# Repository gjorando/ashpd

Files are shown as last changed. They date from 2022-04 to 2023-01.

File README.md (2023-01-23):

# Aperture Science Handheld Portal Device

This repository contains everything needed to craft your very own Portal Gun — at home! 

**WARNING: This build is in alpha state. There are a lot of issues and some tinkering may be needed to get an assembled device.**

## Repository tree

* `ashpd_firmware/`: Micropython code that runs on an ESP32. The firmware handles some lights and sound effects. A PyCharm project is included, ready to use. I use the MicroPython plug-in to quickly deploy and test my code directly from PyCharm.
* `ashpd_hardware/`: A KiCad (free and open source EDA suite) project I used to design the electronic schematic. A GIMP project (`protoboard layout.xcf`) crudely describes the disposition I picked for the components on a protoboard.
* `decals/`: Vinyl decal designs that I quickly put together. They have kind of an odd format because I sent them for manufacturing to [Sticker mule](https://www.stickermule.com/), which only accepts multiples of 25mm for the size.
* `ender3_cura`: Ultimaker Cura settings for each piece. They are tuned for my own Ender3-V2 printer, so be careful if you want to print the pieces yourself.
* `stl_files`: STL files for each piece. I'd recommend using these files if you want to print them yourself. Import them into your slicer of choice, and fine tune the settings according to what works best for you.
* `portal_gun.FCStd`: The main FreeCAD project which holds the design of each 3D printed component.

## History of the project

## Instructions manual

Coming soon...

### Materials and tools

### 3D printing

### Electronics

### Painting and decoration

### Assembly

## Aknowledgments

* Portal and the Portal logo are trademarks and/or registered trademarks of Valve Corporation. All other trademarks are property of their respective owners. © 2023 Valve Corporation. All rights reserved.
* A huge thank you to [Lucas Lombard](https://github.com/lululombard) for his advice and material support during the conception and construction of this project. I couldn't have done it without you.

## TODO list: minor pieces

- [ ] speaker cover
- [ ] LED ring holder for the barrel
- [ ] LED holder for the rod
- [ ] USB-C support if I cannot manage to make the current cable work

## Roadmap for a V2

* Rebuild from the ground each piece (on either FreeCad or Fusion 360), being more mindful of the dependencies between each operation. The current FreeCAD file is a mess and trying to change some values can break everything.
* Add â way of atemporarily fixing each pièce together instead of relying on hot glue. Actually, the v1 uses heat sealed threaded inserts, but it was a last minute decision that was haphazardly put together. Adding pre-holes for the threaded inserts would be a plus.
* On the rear core lid: add a conduit to directly screw the handle's bottom screw, instead of hacking something with a threaded insert to correct for a design oversight.
* Adjust the tolerance, which was waaay too small: a lot of pieces have to be sanded a lot to fit together.
* Add more cake.

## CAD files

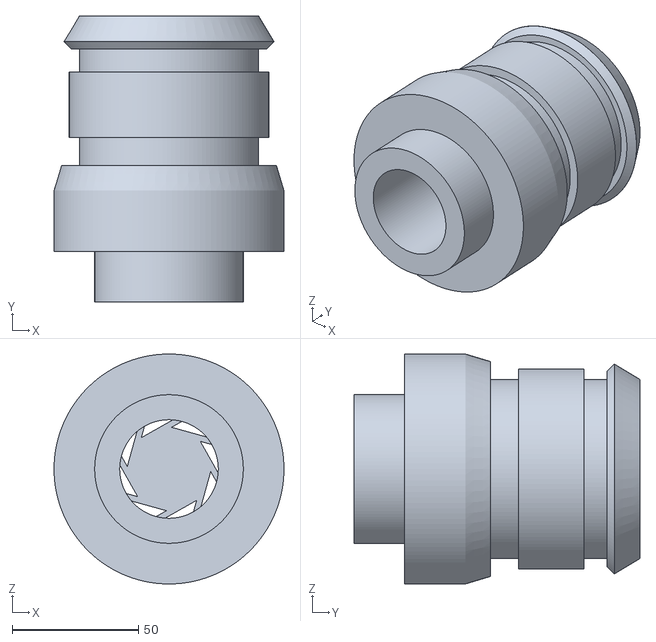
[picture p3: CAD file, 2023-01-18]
stl_files/barrel_main.stl
91.0 x 113.0 x 91.0

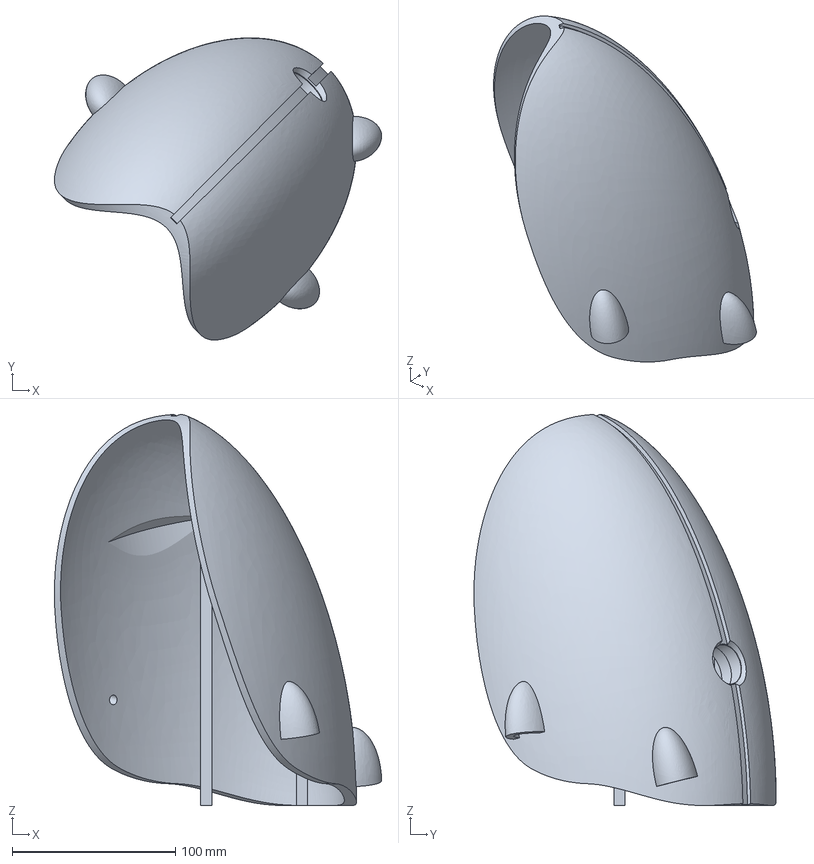
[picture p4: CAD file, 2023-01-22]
ender3_cura/rear_shell.3mf
200.2 x 184.9 x 239.3 mm

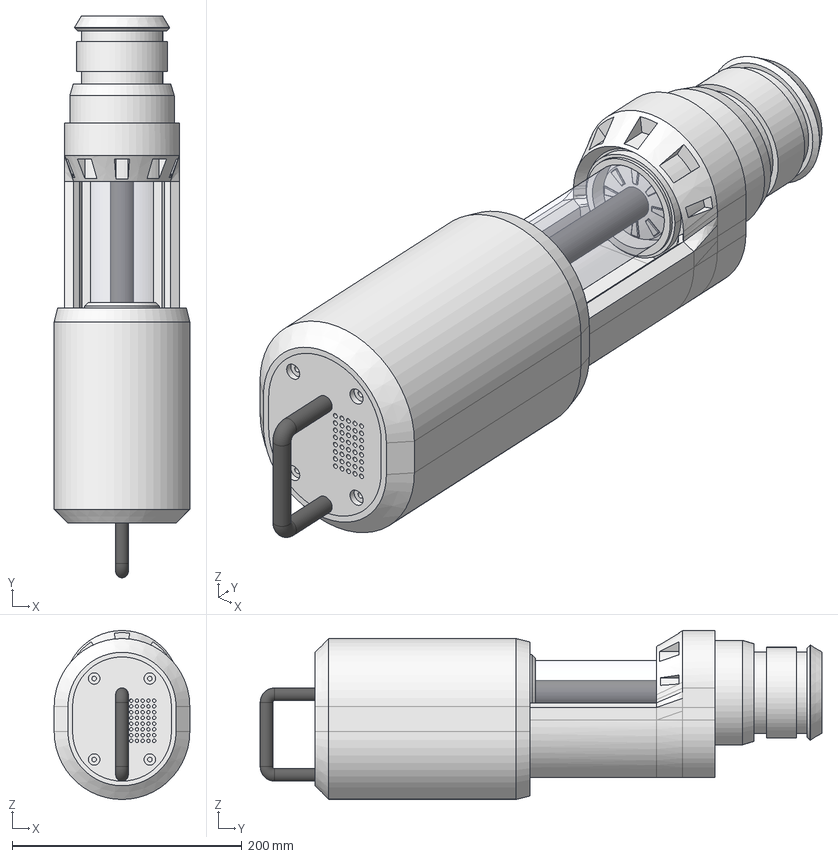
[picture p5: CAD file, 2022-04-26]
freecad/portal_gun.FCStd
118.0 x 488.5 x 147.0 mm
rear_core_body
rear_core_lid
front_core_body
barrel_main
trans_tube
light_rod_body
handle

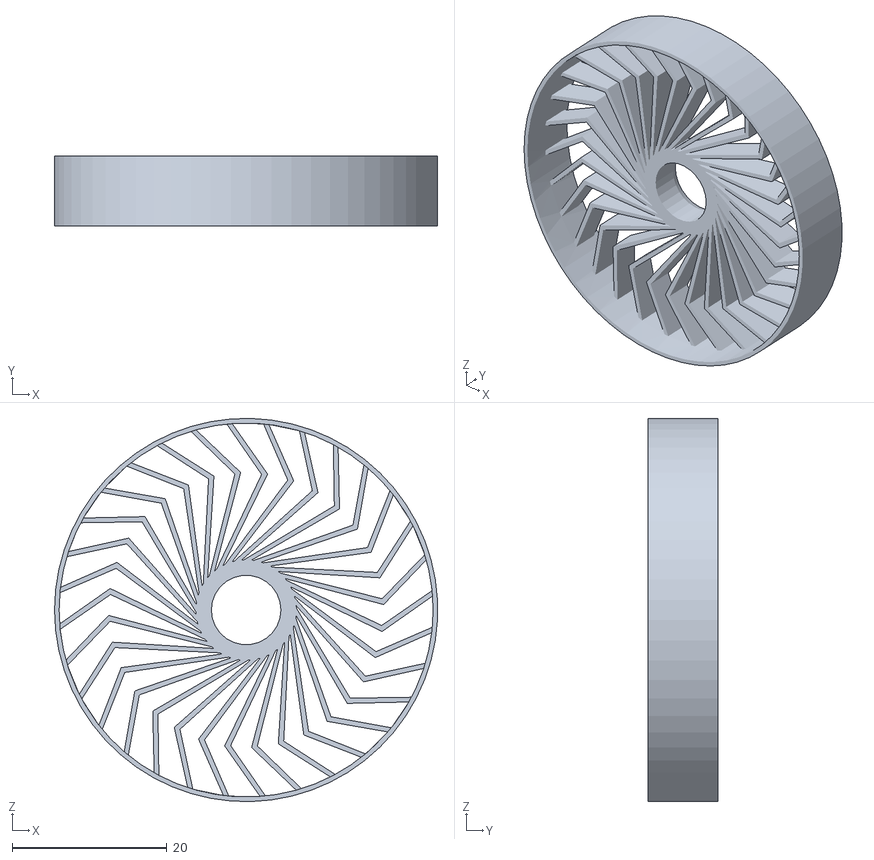
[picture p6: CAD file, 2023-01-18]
stl_files/barrel_pattern.stl
49.6 x 9.00 x 49.6

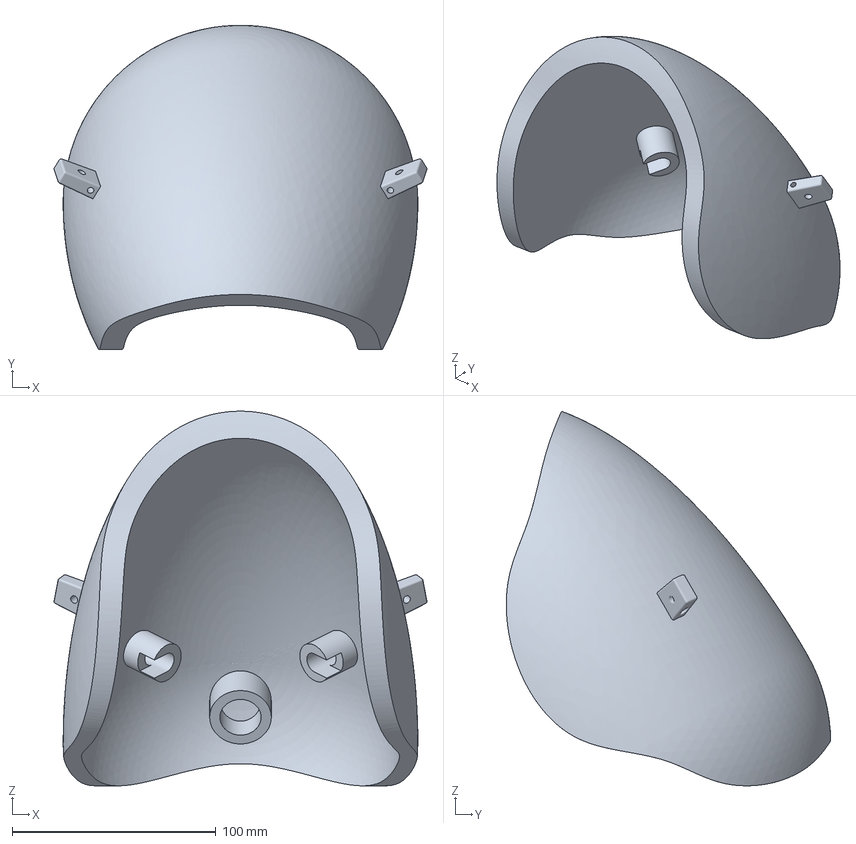
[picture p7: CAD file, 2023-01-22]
ender3_cura/front_shell.3mf
182.9 x 159.1 x 183.7 mm

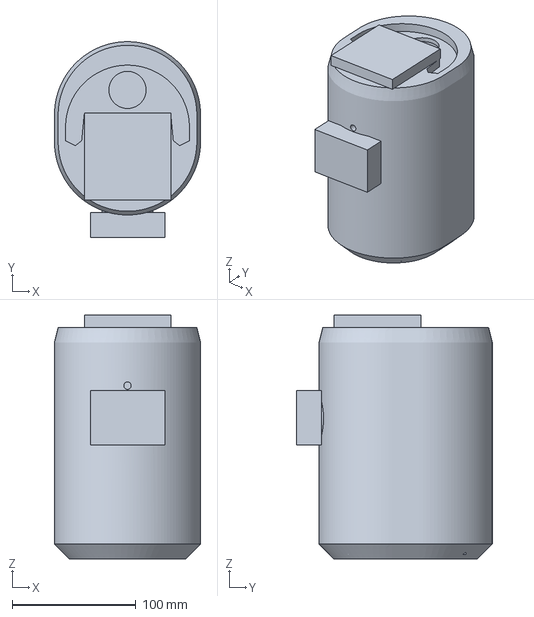
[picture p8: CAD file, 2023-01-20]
ender3_cura/rear_core.3mf
118.0 x 158.0 x 197.1 mm

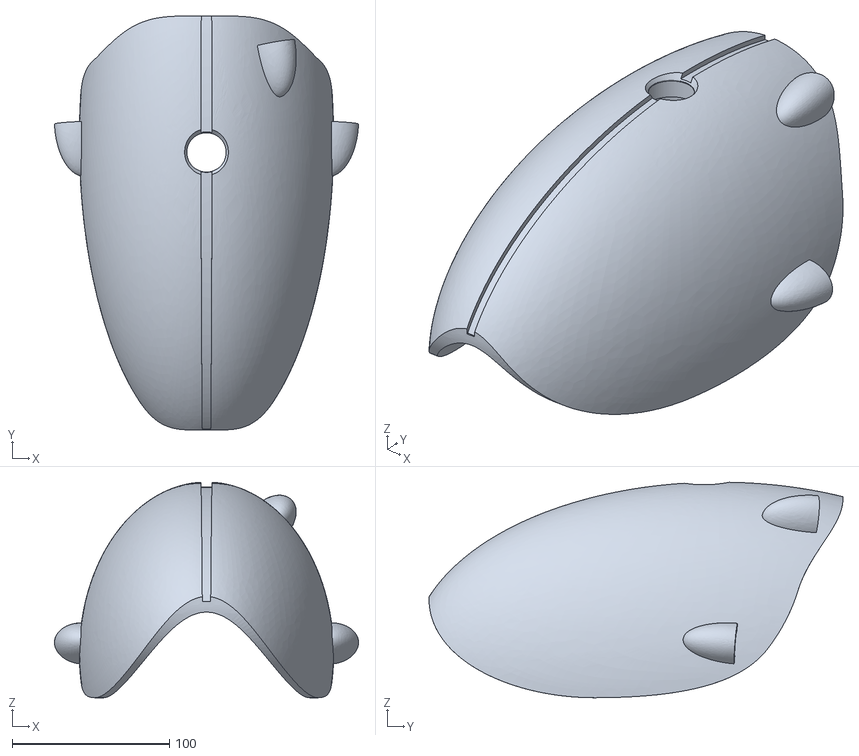
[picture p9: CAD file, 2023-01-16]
stl_files/rear_shell.stl
193.7 x 263.7 x 137.3

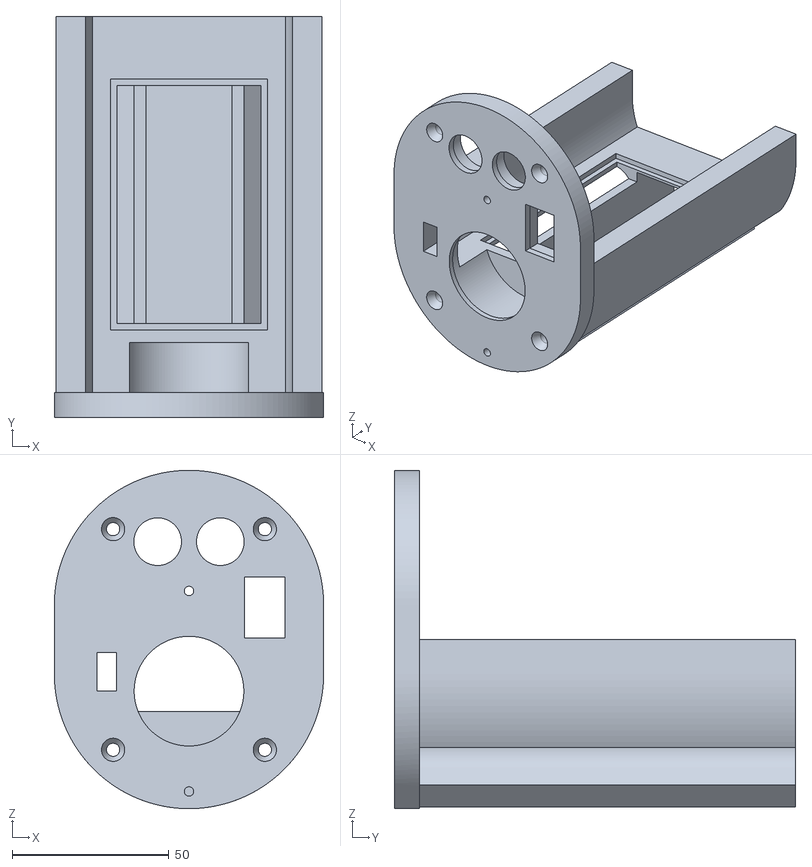
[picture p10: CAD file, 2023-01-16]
stl_files/rear_core_lid.stl
86.0 x 128.0 x 108.0

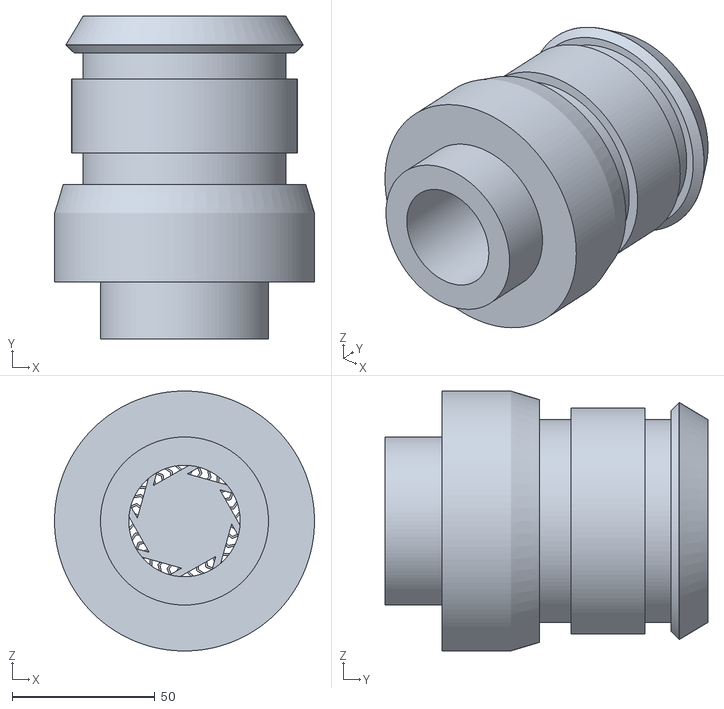
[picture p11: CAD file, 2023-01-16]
stl_files/barrel.stl
91.0 x 113.0 x 91.0

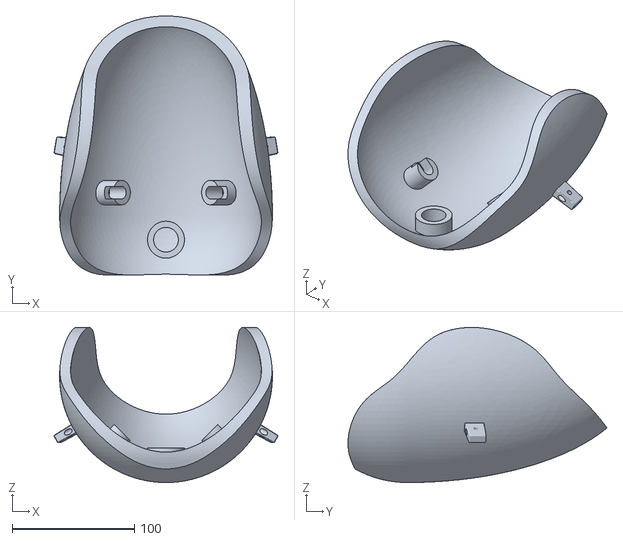
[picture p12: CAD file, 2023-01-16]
stl_files/front_shell.stl
182.9 x 211.7 x 126.8

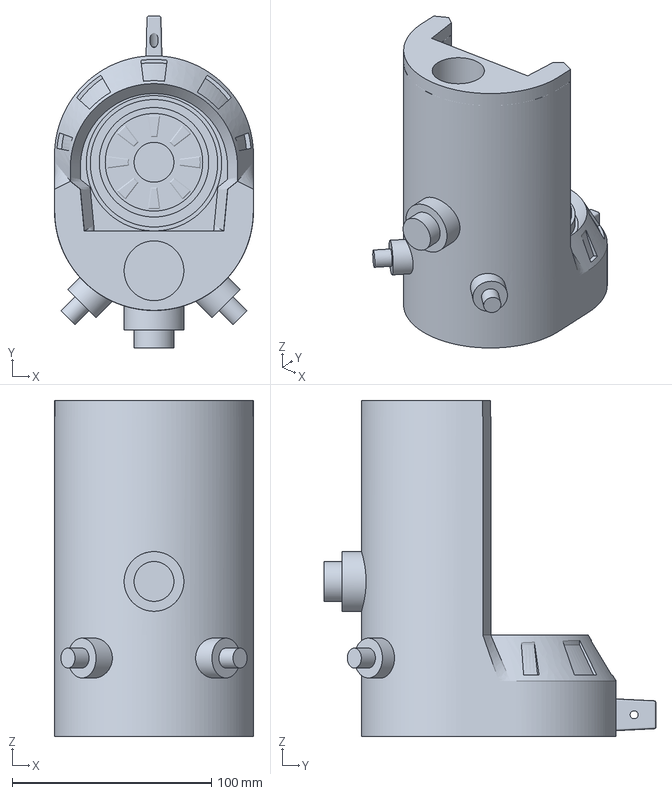
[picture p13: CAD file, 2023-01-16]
ender3_cura/front_core.3mf
100.0 x 166.8 x 169.0 mm

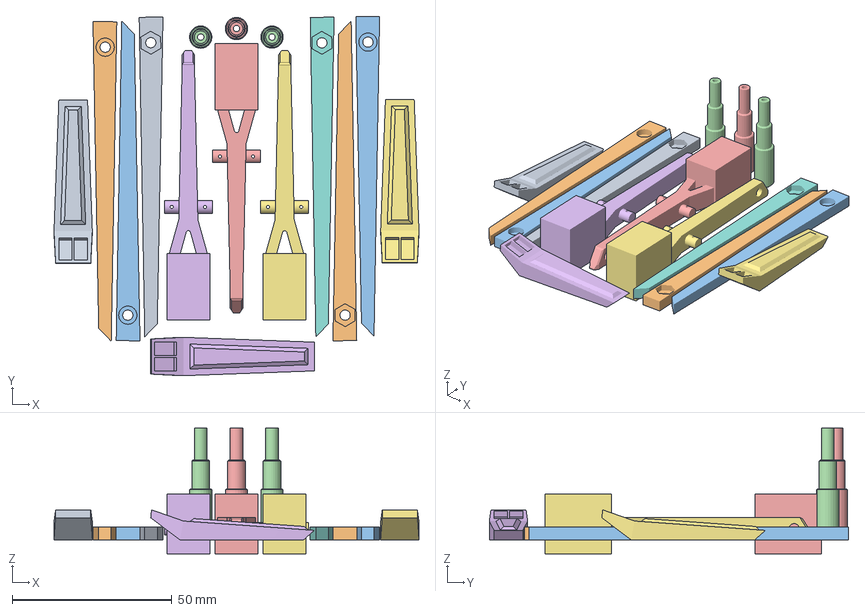
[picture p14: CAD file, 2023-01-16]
ender3_cura/fingers.3mf
114.2 x 112.5 x 39.4 mm
finger_tip.stl
finger_body_R.stl
finger_body_L.stl
finger_insert.stl
finger_base.stl
finger_tip.stl(1)
finger_tip.stl(2)
finger_body_R.stl(1)
finger_body_R.stl(2)
finger_body_L.stl(1)
finger_body_L.stl(2)
finger_insert.stl(1)
finger_insert.stl(2)
finger_base.stl(1)
finger_base.stl(2)

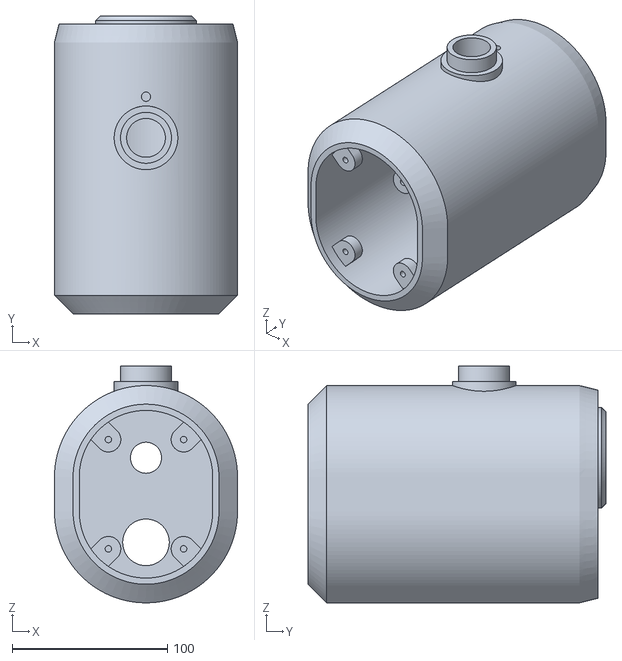
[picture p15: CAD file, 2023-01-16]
stl_files/rear_core.stl
118.0 x 192.0 x 152.5

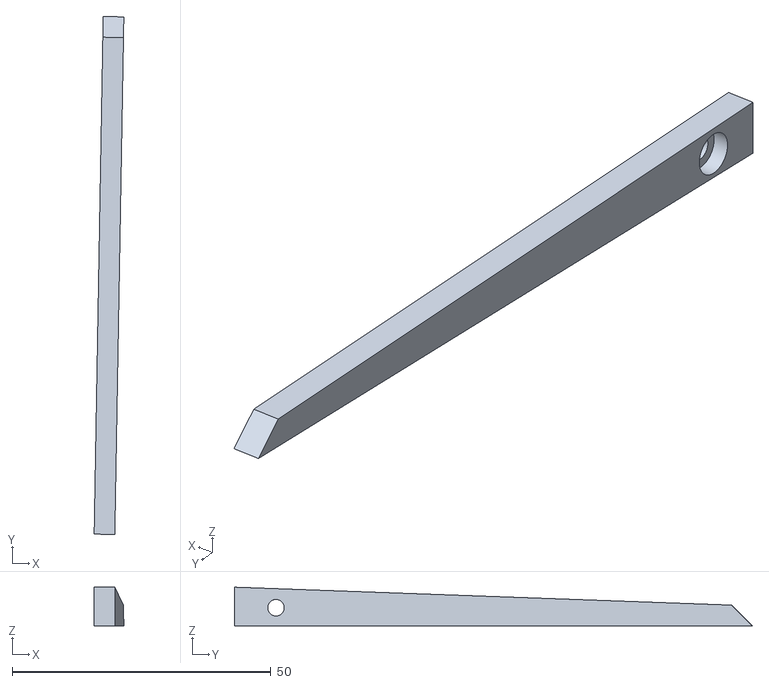
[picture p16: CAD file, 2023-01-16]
stl_files/finger_body_L.stl
5.74 x 100.1 x 7.47

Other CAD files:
ender3_cura/barrel_pattern.3mf
ender3_cura/barrel.3mf
ender3_cura/rear_core_lid.3mf
stl_files/front_core.stl
source_portal_gun.blend
stl_files/finger_base.stl
stl_files/finger_body_R.stl
stl_files/finger_insert.stl
stl_files/finger_tip.stl

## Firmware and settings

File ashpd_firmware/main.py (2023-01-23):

import machine
import neopixel

from wavplayer import WavPlayer

import micropython
micropython.alloc_emergency_exception_buf(100)

# portal colors (please use hexadecimal bytes as Python can autoparse decimal values to 32bit integers)
ORANGE_COLOR = (0xFF, 0x20, 0x00)
BLUE_COLOR = (0x00, 0x65, 0xFF)
# total number of LEDs driven
NUM_LED_STRIP = 32
# timing (high_0, low_0, high_1, low_1)
LED_STRIP_TIMING = (350, 800, 700, 600)

def orange_callback(p):
    """
    Callback for the orange button.

    :param p: Pin.
    """
    global AUDIO_PLAYER
    if AUDIO_PLAYER.isplaying():  # This avoids change while the sound is still playing
        return
    global current_color
    global portal_sound
    portal_sound = "fire_orange.wav"
    current_color = ORANGE_COLOR


def blue_callback(p):
    """
        Callback for the blue button.

        :param p: Pin.
        """
    global AUDIO_PLAYER
    if AUDIO_PLAYER.isplaying():  # This avoids change while the sound is still playing
        return
    global current_color
    global portal_sound
    portal_sound = "fire_blue.wav"
    current_color = BLUE_COLOR


# setup pins
RED_LED_PIN = machine.Pin(23, machine.Pin.OUT)
ORANGE_BTN_PIN = machine.Pin(26, machine.Pin.IN, machine.Pin.PULL_UP)
BLUE_BTN_PIN = machine.Pin(27, machine.Pin.IN, machine.Pin.PULL_UP)
LED_STRIP_PIN = machine.Pin(22, machine.Pin.OUT)
LRCLK_PIN = machine.Pin(18)
BCLK_PIN = machine.Pin(19)
AUDIO_PIN = machine.Pin(21)


# button callbacks
ORANGE_BTN_PIN.irq(handler=orange_callback, trigger=machine.Pin.IRQ_FALLING)
BLUE_BTN_PIN.irq(handler=blue_callback, trigger=machine.Pin.IRQ_FALLING)

# turn RED LEDs on
RED_LED_PIN.on()

# setup led strip
LED_STRIP = neopixel.NeoPixel(LED_STRIP_PIN, NUM_LED_STRIP, timing=LED_STRIP_TIMING)
current_color = ORANGE_COLOR

# setup audio
# AUDIO_BUS = machine.I2S(0, mode=machine.I2S.TX, bits=16, format=machine.I2S.STEREO, rate=441000, ibuf=20000)
AUDIO_PLAYER = WavPlayer(id=0, sck_pin=BCLK_PIN, ws_pin=LRCLK_PIN, sd_pin=AUDIO_PIN,
                         ibuf=40000, root="/")
play_init = True
portal_sound = None

# TODO implement boot animations on the strip LED
while True:
    if current_color and not AUDIO_PLAYER.isplaying():
        LED_STRIP.fill(current_color)
        LED_STRIP.write()
        if portal_sound:
            AUDIO_PLAYER.play(portal_sound, loop=False)
        current_color = None

    if play_init:
        AUDIO_PLAYER.play("startup_sound.wav", loop=False)
        play_init = False

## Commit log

2018-01-29 Separated variables from modules in openscad files
    [2.1.scad, globals.scad, printsheet.scad]
2018-01-29 Extrude pieces
    [2.1.scad]
2018-01-29 Added piece 2.7 (rear core reinforcement bar)
    [2.1.scad, 2.7.scad, globals.scad]
2018-01-29 Added 2.7 to printhseet
    [globals.scad, printsheet.scad]
2018-01-29 Added piece 2.6 (rear core secondary reinforcement bar)
    [2.6.scad, printsheet.scad]
2018-01-29 Using intermediary backplates
    [2.1b.scad, 2.7.scad, globals.scad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]
2018-02-01 Added information headers in each file
    [2.1.scad, 2.1b.scad, 2.2.scad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]
2018-02-01 Added piece 2.2 (rear core screw holder)
    [2.1.scad, 2.2.scad, globals.scad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]
2018-02-01 Fix path in header
    [2.1.scad, 2.1b.scad, 2.2.scad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]
2018-02-01 Added piece 2.1c (rear core backplate with screw holes)
    [2.1.scad, 2.1c.scad, printsheet.scad]
2018-02-01 Added pieces 2.3 and 2.3b (cover casing)
    [2.3.scad, 2.3b.scad, printsheet.scad]
2018-02-04 Better placement of pieces
    [2.1.scad, 2.1b.scad, 2.2.scad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]
2018-02-04 Using nut holes
    [2.1c.scad, globals.scad]
2018-02-04 Added holes for the attaching rod of the rear shell
    [2.1.scad, 2.1b.scad, globals.scad]
2018-02-04 Added assembly demonstration file
    [assembly.scad]
2018-02-04 Added piece 2.8 (front plate)
    [2.8.scad, assembly.scad, globals.scad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]
2018-02-04 Drafted pieces 2.4 and 2.5 (cover)
    [2.1c.scad, 2.2.scad, 2.4.scad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]
2018-02-04 Completed cover
    [2.4.scad, globals.scad, printsheet.scad]
2018-02-04 Added a dummy handle on the assembly model
    [assembly.scad, globals.scad]
2018-02-07 Drafting pieces 2.9 and 2.9b (junction plates)
    [2.9.scad, 2.9b.scad, assembly.scad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]
2018-02-07 Moved holes on cover, bigger screw hole support
    [2.1c.scad, 2.2.scad, 2.4.scad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]
2018-02-07 Drafted hole on the junction plates
    [2.9.scad, globals.scad, printsheet.scad]
2018-03-04 Added piece 1A.1 (back plate of the front core)
    [1A.1.scad, 2.8.scad, assembly.scad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]
2018-04-02 Added pieces 1A.2-4 (inner wall and inner floor, nut plate for junction with the rear core)
    [1A.1.scad, 1A.2.scad, 1A.3.scad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]
2022-04-23 Getting back to work, recreating pieces on FreeCAD
    [2.4.scad, assembly.scad, portal_gun_blueprints_white_and_blue.blend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]
2022-04-24 Rear core main part
    [globals.scad, rear_core_main.FCStd]
2022-04-24 Drafting the rear core lid
    [rear_core_main.FCStd]
2022-04-24 Working on the front core
    [assembly.scad, portal_gun.FCStd, rear_core_main.FCStd]
2022-04-25 Refined the curved section of the front core
    [portal_gun.FCStd]
2022-04-25 front_core insert for tube and rod
    [portal_gun.FCStd]
2022-04-25 Detailing on the front core
    [portal_gun.FCStd]
2022-04-26 Detailing on the rear core
    [portal_gun.FCStd]
2022-04-26 Added a cosmetic handle
    [portal_gun.FCStd]
2022-04-26 Venting holes on the front core
    [portal_gun.FCStd]
2022-04-29 Before inner hole
2022-04-29 Placed inner hole w/o bool
2022-05-03 Deleted old openscad files, added wire routing
    [1A.1.scad, 1A.2.scad, 1A.3.scad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]
2022-05-03 Added hole for the lens in the rear shell
2022-05-04 Finished the lens hole and attachment with the rear core
2022-05-06 finger insert on the front core
2022-05-07 Finger part 5C
2022-05-07 Finger: parts 5B L and R done
2022-05-07 Switched to a license that actually makes sense
2022-05-08 Finger done
2022-05-09 LED holes, fixed the small artifact on the back of the rear core
2022-05-09 Adjusted the screw holes for the back lid
2022-05-09 Adjusting lens hole (can be modified, depending of the final lens used)
2022-05-11 Tubular insert for the wires, improved the front core
2022-05-12 Adjusted a lot of lengths for the nuts and bolts
2022-05-13 Adjusted the finger base
2022-05-13 Added wiring routing on the rear shell and core
2022-05-14 lens insert
2022-05-15 Experimenting with cura
    [rear_shell.3mf]
2022-05-20 Working on the front shell
    [rear_shell.3mf]
2022-05-21 Splitting hulls
2022-05-21 Done splitting hulls
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2022-12-15 Added LED support on the front shell
2022-12-15 Version 1 is done. Now we need to fine tune some parameters depending on the non 3D printed pieces.
2023-01-05 Setup for firmware development, first version for the hardware schematic
    [ashpd_hardware.kicad_pcb, ashpd_hardware.kicad_sch]
2023-01-15 Finished micropython firmware, updated to ESP32 for I2S support with MicroPython
    [ashpd_hardware.kicad_sch]
2023-01-16 Protoboard layout, updated TODO-list
    [ashpd_hardware.kicad_sch]
2023-01-16 Added stl and cura files for the finger parts
    [finger_base.stl, finger_body_L.stl, finger_body_R.stl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]
2023-01-16 Added stl for the remainder of the pieces
    [barrel.stl, front_core.stl, front_shell.stl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]
2023-01-16 Added slicer settings for the remainder of the pieces
    [barrel.3mf, front_core.3mf, front_shell.3mf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]
2023-01-17 Print rear core and its lid separately
    [barrel.3mf, rear_core.3mf, rear_core_lid.3mf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]
2023-01-18 Cura config for hotfix
    [barrel_pattern_fix.3mf]
2023-01-18 Turned the hotfix into a permanent solution
    [barrel.3mf, barrel_main.stl, barrel_pattern.3mf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]
2023-01-18 Corrected the adjustment between the barrel and its pattern
    [barrel_pattern.3mf, barrel_pattern.stl]
2023-01-18 Corrected the barrel pattern and print settings
    [barrel_pattern.3mf, barrel_pattern.stl, front_shell.3mf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]
2023-01-18 Optimized the print settings for the rear core
    [rear_core.3mf]
2023-01-20 Fixed a hardware bug due to wrong pinout labelling on my ESP32-WROOM
    [main.py]
2023-01-20 Minor update to the slicer parameters
    [rear_core.3mf]
2023-01-22 Modified slicer settings for the shells
    [front_shell.3mf, rear_shell.3mf]
2023-01-23 Added a condition in the irq callback to avoid firing a sound effect twice in a row
    [main.py]
